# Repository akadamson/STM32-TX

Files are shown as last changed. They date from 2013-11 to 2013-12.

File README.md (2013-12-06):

# STM32-TX - Integration of STM32 and a couple of Radio chipsets

#### NOTICE: Non-functional at the moment, work in process ####

20130821 - beginning schematic capture - ADF7012 is pretty much complete on the radio side 
         - Note this is a VHF implementation at the moment with the final filter components, etc.

20131201 - added SIradio directory with v0.1 4464 radio.  Notes: is 3v3 only but could work on a pro-mini if 3v3 version.  Laid our for STM32-MiniF3 as a daughter card mate (sandwich).  This version is 144mhz version

20131204 - updates SIradio with v0.2 4464 radio version… Nothing significant, just fixed some trace widths, some routing and added some silkscreen to the bottom of the board… Still working on final version ready for a board build.

20131205 - changed the VCXO to the *tiny* version and verified the footprint (which was wrong prior :( ).

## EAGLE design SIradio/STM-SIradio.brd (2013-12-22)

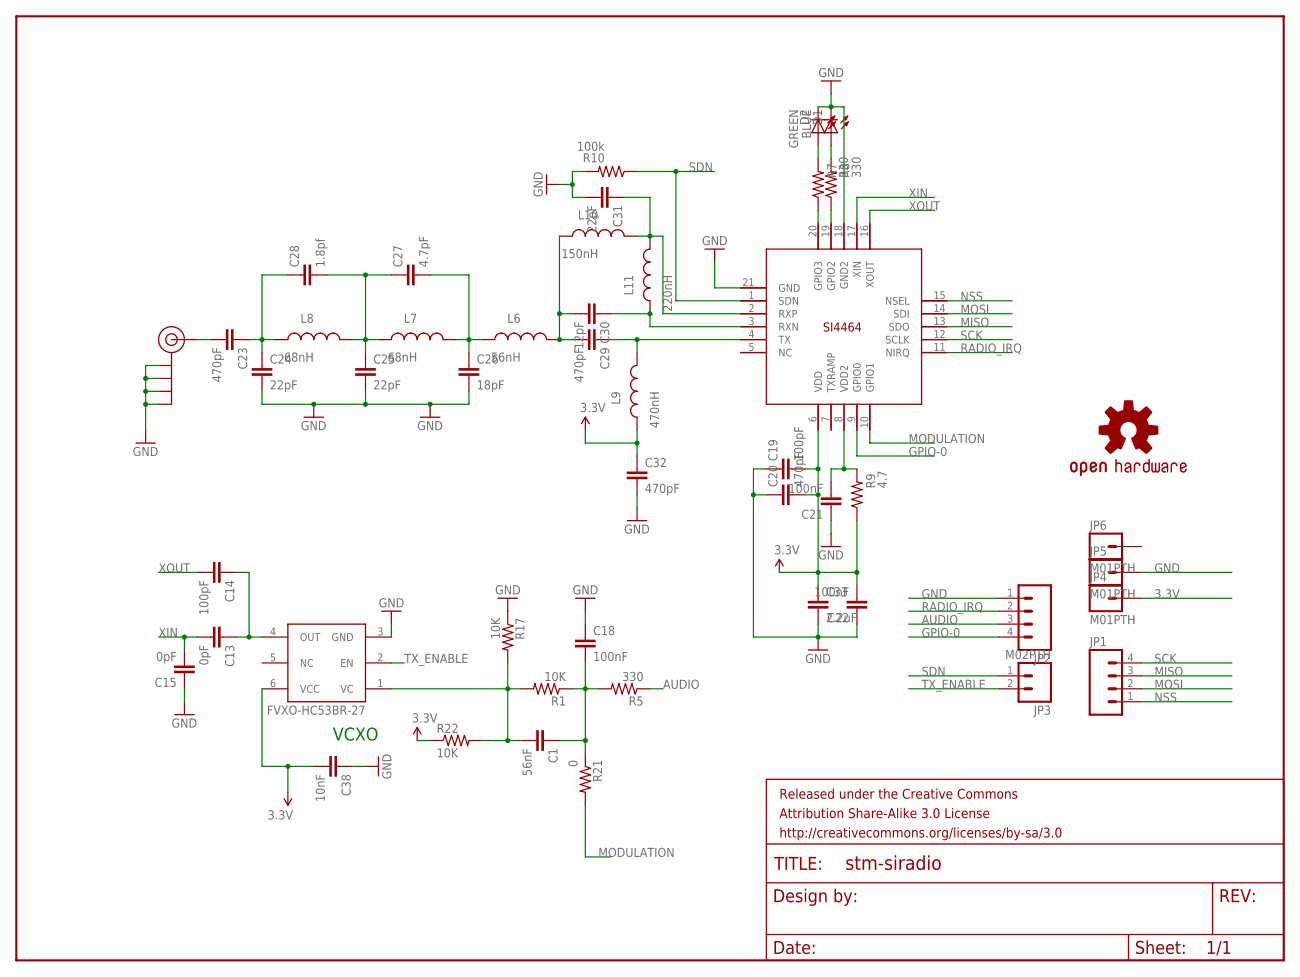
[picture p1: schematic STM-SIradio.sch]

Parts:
C1: 56nF; 0603-CAP
C13, C15: 0pF; 0603-CAP
C14, C19: 100pF; 0603-CAP
C18, C21, C22: 100nF; 0603-CAP
C20, C23, C29, C32: 470pF; 0603-CAP
C24, C25, C31: 22pF; 0603-CAP
C26: 18pF; 0603-CAP
C27: 4.7pF; 0603-CAP
C28: 1.8pf; 0603-CAP
C30: 12pF; 0603-CAP
C33: 2.2uF; 1206
C38: 10nF; 0603-CAP
D1: BLUE; LED-0603
D2: GREEN; LED-0603
FRAME1: FRAME-LETTER; CREATIVE_COMMONS
FVXO-HC53BR-27: VCXO-SMDSMD3X; VCXO-SMD-5X3.2
J$2: SMA_EDGE; SMA-EDGE
JP1, JP2: M04PTH; 1X04
JP3: M02PTH; 1X02
JP4, JP5, JP6: M01PTH; 1X01
L6: 56nH; 0603
L7, L8: 68nH; 0603
L9: 470nH; 0603
L10: 150nH; 0603
L11: 220nH; 0603
LOGO1: OSHW-LOGOL; OSHW-LOGO-L
R1, R17, R22: 10K; 0603-RES
R5, R7, R8: 330; 0603-RES
R9: 4.7; 0603-RES
R10: 100k; 0603-RES
R21: 0; 0603-RES
U$3: SI4464; QFN20+GNDPAD

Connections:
3.3V: C19.2, C20.2, C22.2, C32.1, C33.1, C38.2, FVXO-HC53BR-27.6 (VCC), JP4.1, L9.1, R9.1, R22.1, U$3.6 (VDD)
AUDIO: JP2.3, R5.1
GND: C15.1, C18.1, C19.1, C20.1, C21.1, C22.1, C24.2, C25.2, C26.2, C31.2, C32.2, C33.2, C38.1, D1.C, D2.C, FVXO-HC53BR-27.3 (GND), J$2.GND@0 (GND), J$2.GND@1 (GND), J$2.GND@2 (GND), J$2.GND@3 (GND), JP2.1, JP5.1, R10.2, R17.1, U$3.18 (GND2), U$3.21 (GND)
GPIO-0: JP2.4, U$3.9 (GPIO0)
MISO: JP1.3, U$3.13 (SDO)
MODULATION: R21.2, U$3.10 (GPIO1)
MOSI: JP1.2, U$3.14 (SDI)
unnamed: C1.2, FVXO-HC53BR-27.1 (VC), R1.2, R17.2, R22.2
unnamed: C1.1, C18.2, R1.1, R5.2, R21.1
unnamed: C13.1, C14.1, FVXO-HC53BR-27.4 (OUT)
unnamed: C23.2, J$2.SIG (SIGNAL)
unnamed: C23.1, C24.1, C28.1, L8.1
unnamed: C25.1, C27.1, C28.2, L7.1, L8.2
unnamed: C26.1, C27.2, L6.1, L7.2
unnamed: C29.1, L9.2, U$3.4 (TX)
unnamed: C29.2, C30.2, L6.2, L10.1
unnamed: C30.1, L11.1, U$3.3 (RXN)
unnamed: C31.1, L10.2, L11.2, U$3.2 (RXP)
unnamed: D1.A, R8.2
unnamed: D2.A, R7.2
unnamed: R7.1, U$3.20 (GPIO3)
unnamed: R8.1, U$3.19 (GPIO2)
unnamed: C21.2, R9.2, U$3.8 (VDD2)
NSS: JP1.1, U$3.15 (NSEL)
RADIO_IRQ: JP2.2, U$3.11 (NIRQ)
SCK: JP1.4, U$3.12 (SCLK)
SDN: JP3.1, R10.1, U$3.1 (SDN)
TX_ENABLE: FVXO-HC53BR-27.2 (EN), JP3.2
XIN: C13.2, C15.2, U$3.17 (XIN)
XOUT: C14.2, U$3.16 (XOUT)

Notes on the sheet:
VCXO

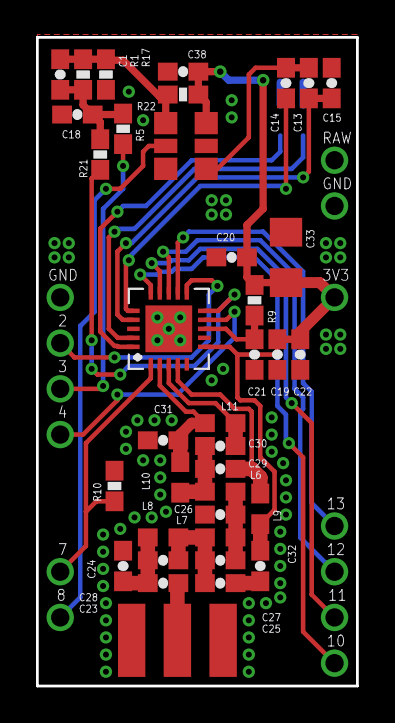
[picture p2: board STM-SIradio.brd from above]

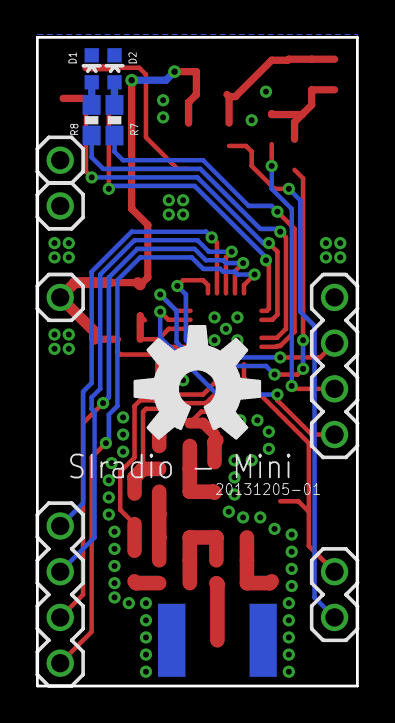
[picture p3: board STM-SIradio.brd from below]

Board: 2 copper layers, 17.8 x 36.0 mm, 49 parts (11 on the bottom side), 30 nets.

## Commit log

2013-11-20 work in process
    [STM32-TX.brd, STM32-TX.sch]
2013-12-02 updated for SIradio version in noted directory
    [STM-SIradio.brd, STM-SIradio.sch]
2013-12-04 updated with v0.2 - see Readme for details
    [STM-SIradio.brd, STM-SIradio.sch]
2013-12-05 few more tweaks
    [STM-SIradio.brd]
2013-12-06 Updated with new VCXO footprint, seen readme for other specifics
    [STM-SIradio.brd, STM-SIradio.sch]
2013-12-13 updated silkscreen on SIradio
    [STM-SIradio.brd]
2013-12-22 First Version - PCB produced
    [STM-SIradio.brd, STM-SIradio.sch]

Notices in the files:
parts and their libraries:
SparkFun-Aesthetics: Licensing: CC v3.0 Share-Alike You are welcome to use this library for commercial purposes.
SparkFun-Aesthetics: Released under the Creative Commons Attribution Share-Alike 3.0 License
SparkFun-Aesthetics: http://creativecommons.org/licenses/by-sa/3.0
